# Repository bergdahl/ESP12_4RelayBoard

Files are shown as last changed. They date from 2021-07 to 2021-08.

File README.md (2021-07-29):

# ESP12_4RelayBoard

This is a simple ESP-12 based 4 relay board I designed to be used in Home Assistant. It is powered by 5V over a micro USB connector,
and switches loads at up to the rated voltage of the relay - 28V/10A, although I recommend limiting the power to max 6 Amps per channel.
Also, the screw connectors used are rated at maximum 15A, so you need to keep the _total combined_ power usage under that limit.

> NOTE: This PCB is _NOT_ designed to be used for mains voltage!

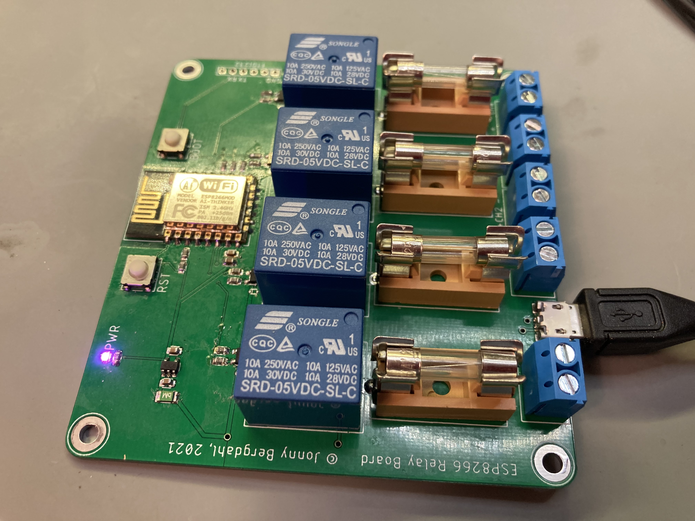
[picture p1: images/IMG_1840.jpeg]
Board


## PCB files

I have added the Gerber files in the `PCB/Gerber` folder, just zip and upload to your favorite PCB manufacturer.

I have also included the EAGLE design files if you need to modify the design for yoyr needs.

## Firmware

I use ESPHome to set it up, which is the easiest way for it to show up in Home Assistant. 

Change the `esphome` section to this:

```
esphome:
  name: relay1
  platform: ESP8266
  board: esp12e
```
Add the following section to add the relays as switches in Home Assistant.

```
switch:
  - platform: gpio
    name: "Relay1"
    pin: GPIO4
  - platform: gpio
    name: "Relay2"
    pin: GPIO5
  - platform: gpio
    name: "Relay3"
    pin: GPIO12
  - platform: gpio
    name: "Relay4"
    pin: GPIO13
```

### Flashing the board

You will need a USB-Serial adapter for initial upload of the firmware, and use the [ESPHome-Flasher](https://github.com/esphome/esphome-flasher) flashing utility.

 - Compile and download the firmware to your local machine.
 - Connect the serial adapter to the board, the board is designed for the pinout of standard FT232RL adapters.
 - Hold down the BOOT button, tap the RST button and then let go of RST. This puts the ESP-12 module in bootloader mode ready for firmware upload.
 - Start ESPHome-Flasher, select the firmware file and the proper COM port and click _Flash ESP_.

## Enclosure

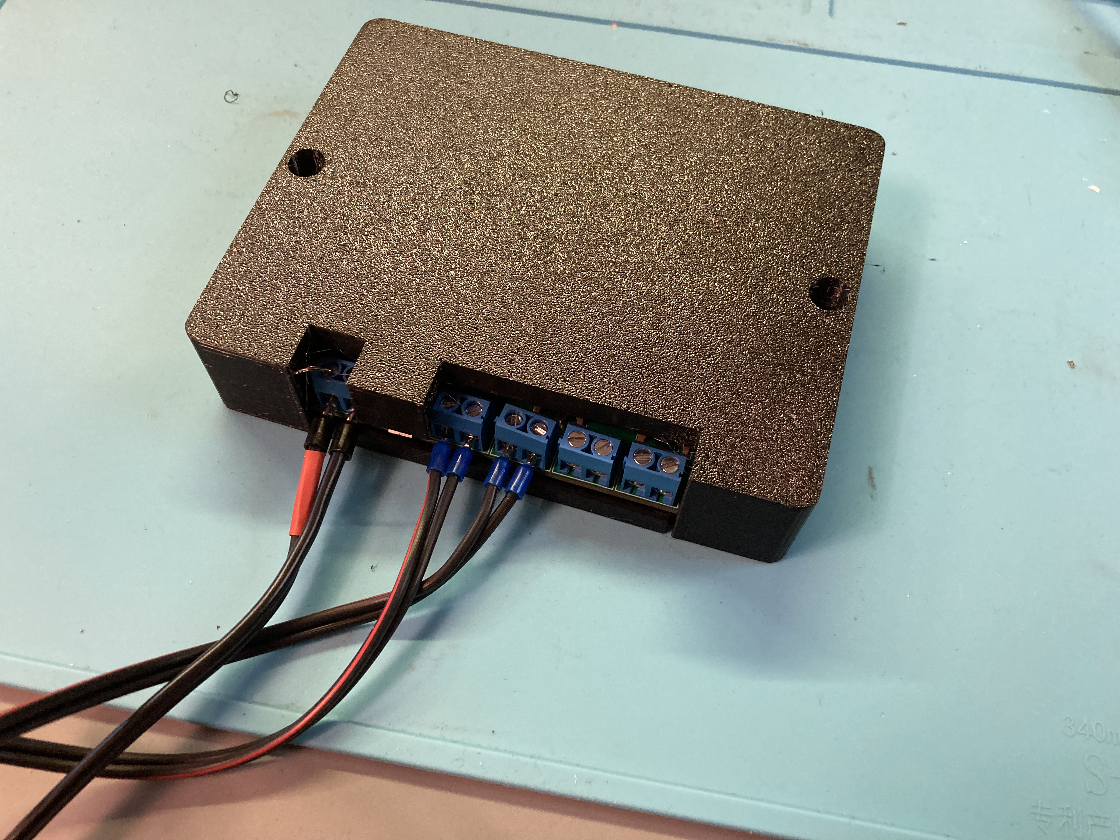
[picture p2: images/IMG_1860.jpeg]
Enclosure


I designed a simple enclosure for 3D printing, available as STL files in the `Enclosure` folder. 

I also included the Fusion360 design file if you need to modify the design for your usage.

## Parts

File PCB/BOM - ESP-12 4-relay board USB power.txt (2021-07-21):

Qty Value            Device                        Package              Parts                                 Description                                                                                   
4   100R             RESISTOR0603                  R0603                R5, R7, R9, R11                                                                                                                     
1   100nF            CAPC0603                      C0603                C4                                                                                                                                  
1   100uF            CAPC0603                      C0603                C1                                                                                                                                  
9   10K              RESISTOR0603                  R0603                R1, R2, R3, R4, R6, R8, R10, R12, R15                                                                                               
1   1K               RESISTOR0603                  R0603                R13                                                                                                                                 
4   1N4148WX-TP      DIODE1N4148WX-TP              SOD-323              D1, D2, D3, D4                                                                                                                      
2   1uF              CAPC0603                      C0603                C2, C3                                                                                                                              
4   2N7702P          MOSFET-NCHSOT23-3             SOT23-3              Q1, Q2, Q3, Q4                                                                                                                      
1   500mA            PTC0ZCJ                       PTC-0ZCJ-1206        F5                                                                                                                                  
1   AP2112K-3.3TRG1  REGULATOR-AP2112KK-SOT23-5    SOT23-5              U2                                                                                                                                  
1   BOOT             TACT-SWITCHEVQ                TACT-SWITCH-EVQ      X1                                                                                                                                  
1   ESP-12           ESP-12E                       ESP-12E              U1                                                                                                                                  
4   FUSE             FUSETEAL                      FUSE-TEAL            F1, F2, F3, F4                        https://www.aliexpress.com/item/1005001704678944.html                                                                                              
1   HEADER-FTDI232   HEADER-FTDI232                FTDI232-1X06         X4                                                                                                                                  
1   IN               TERMINAL-1X02-5.08OSTTC022162 ONSHORE-OSTTC022162  J3                                    https://www.digikey.se/product-detail/sv/on-shore-technology-inc/OSTTC022162/ED2609-ND/614558 
4   MOUNTHOLE-PAD3.2 MOUNTHOLE-PAD3.2              3.2-PAD              H1, H2, H3, H4                                                                                                                      
1   OUT1             TERMINAL-1X02-5.08OSTTC022162 ONSHORE-OSTTC022162  J1                                    https://www.digikey.se/product-detail/sv/on-shore-technology-inc/OSTTC022162/ED2609-ND/614558 
1   OUT2             TERMINAL-1X02-5.08OSTTC022162 ONSHORE-OSTTC022162  J2                                    https://www.digikey.se/product-detail/sv/on-shore-technology-inc/OSTTC022162/ED2609-ND/614558 
1   OUT3             TERMINAL-1X02-5.08OSTTC022162 ONSHORE-OSTTC022162  J4                                    https://www.digikey.se/product-detail/sv/on-shore-technology-inc/OSTTC022162/ED2609-ND/614558 
1   OUT4             TERMINAL-1X02-5.08OSTTC022162 ONSHORE-OSTTC022162  J5                                    https://www.digikey.se/product-detail/sv/on-shore-technology-inc/OSTTC022162/ED2609-ND/614558 
1   PINK             LED0603                       LED0603              D5                                    LED (Generic)                                                                                 
1   RST              TACT-SWITCHEVQ                TACT-SWITCH-EVQ      X2                                    https://www.digikey.se/product-detail/sv/panasonic-electronic-components/EVQ-Q2Y03W/P12961SCT-ND/762951
4   SRD-05VDC-SL-C   RELAYSRD-05VDC-SL-C           RELAY-SRD-05VDC-SL-C K1, K2, K3, K4                        https://www.aliexpress.com/wholesale?SearchText=SRD-05VDC-SL-C
1   USB-MICRO-B-FCI  USB-MICRO-B-FCI               USB-MICRO-B-FCI      X3                                    https://www.digikey.se/product-detail/sv/amphenol-icc-fci/10118192-0001LF/609-4613-1-ND/2785378

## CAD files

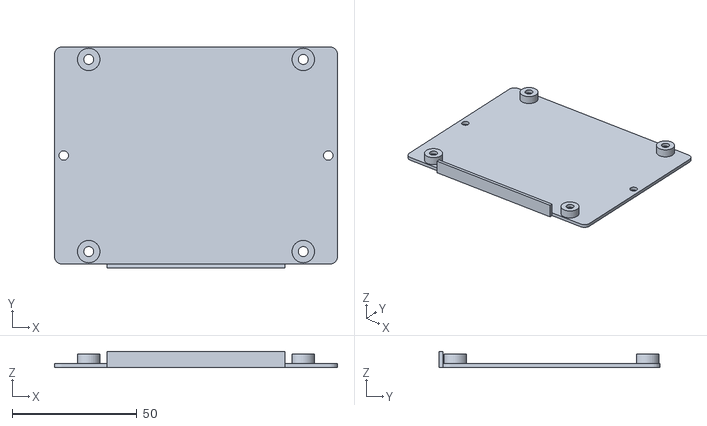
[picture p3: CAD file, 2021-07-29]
Enclosure/ESP-12 4-Relay Board 5V Enclosure - Bottom.stl
113.4 x 88.6 x 6.60

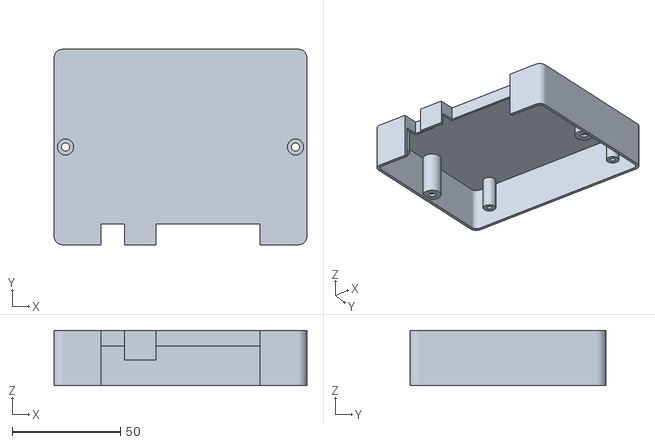
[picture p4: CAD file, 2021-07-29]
Enclosure/ESP-12 4-Relay Board 5V Enclosure - Top.stl
116.6 x 90.2 x 25.4

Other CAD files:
Enclosure/ESP-12 4-Relay Board 5V Enclosure.f3d

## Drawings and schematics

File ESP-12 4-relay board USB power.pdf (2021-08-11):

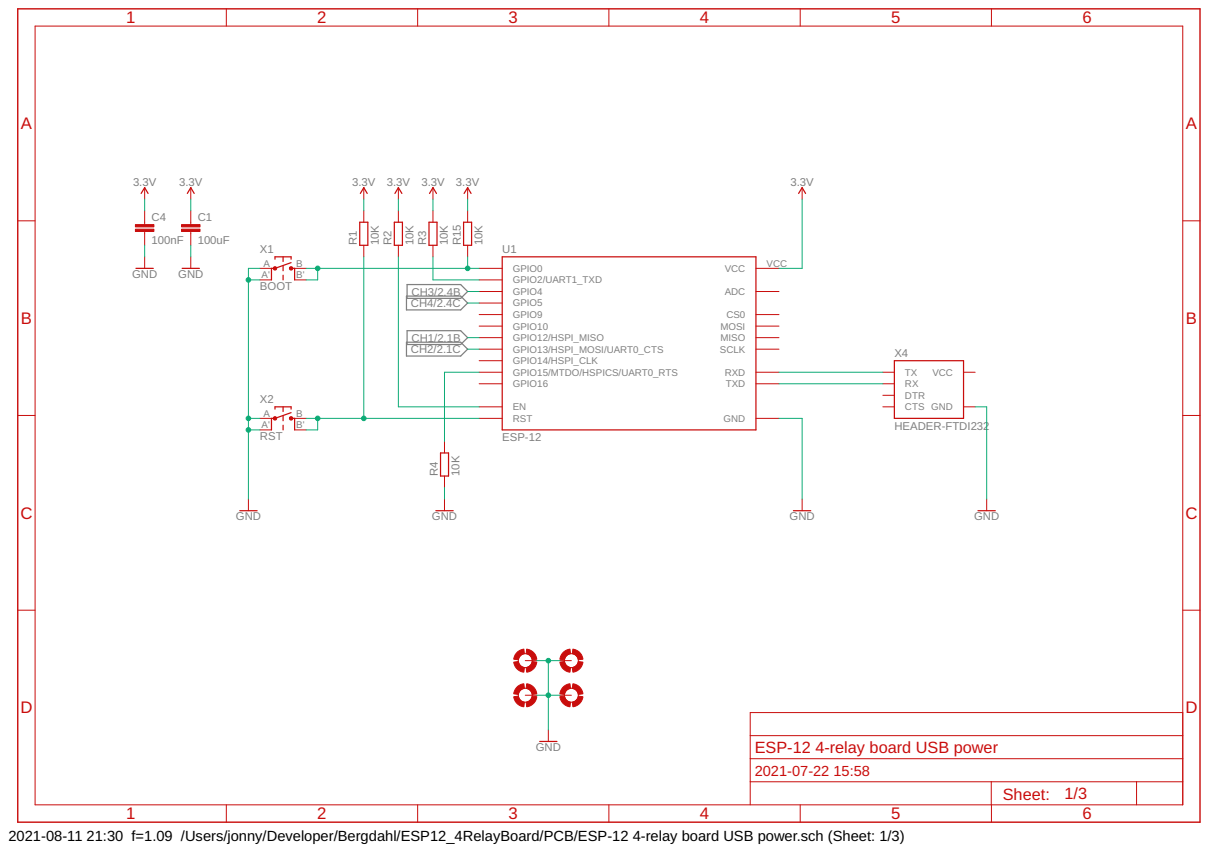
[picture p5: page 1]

ESP-12 4-relay board USB power

2021-08-11 21:30 f=1.09 /Users/jonny/Developer/Bergdahl/ESP12_4RelayBoard/PCB/ESP-12 4-relay board USB power.sch (Sheet: 1/3)

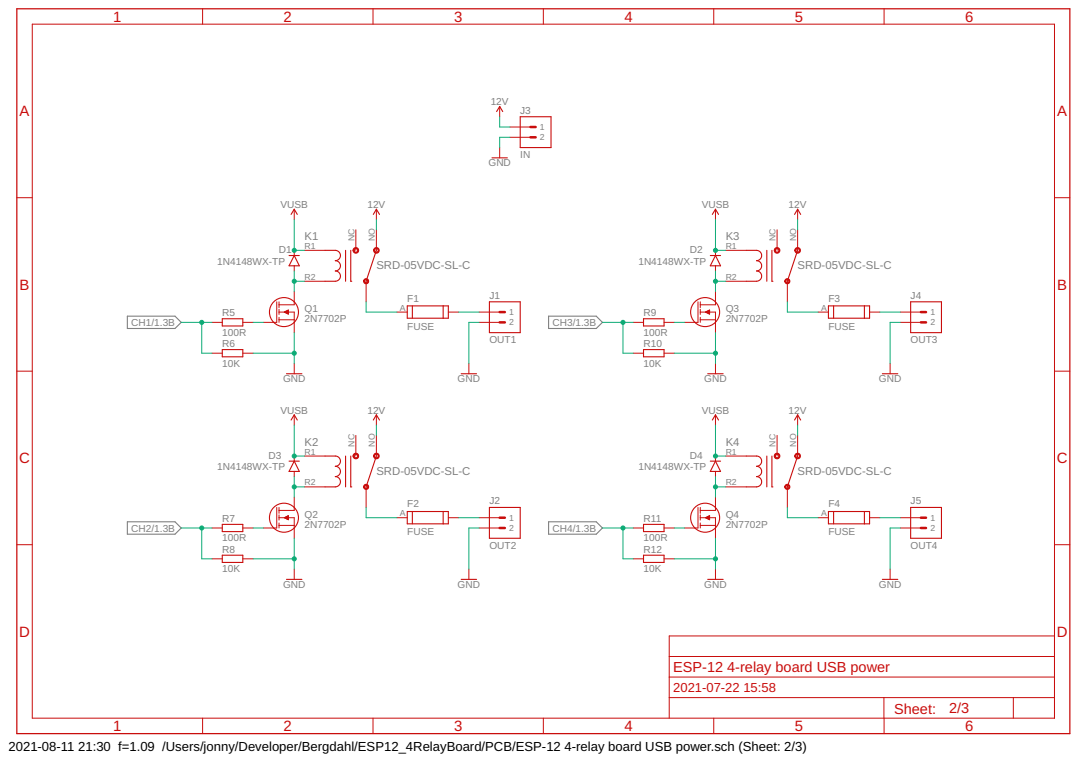
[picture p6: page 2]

ESP-12 4-relay board USB power

2021-08-11 21:30 f=1.09 /Users/jonny/Developer/Bergdahl/ESP12_4RelayBoard/PCB/ESP-12 4-relay board USB power.sch (Sheet: 2/3)

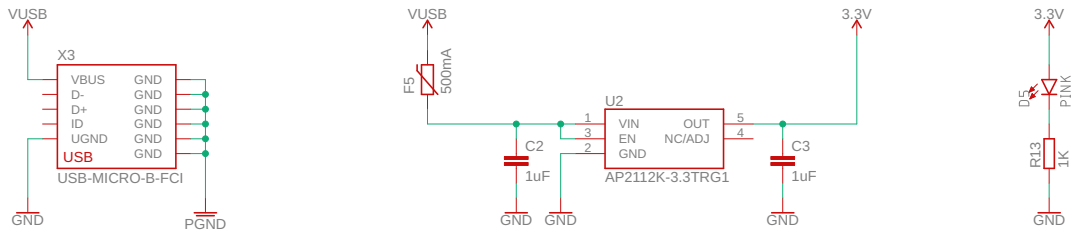
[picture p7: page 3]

ESP-12 4-relay board USB power

2021-08-11 21:30 f=1.09 /Users/jonny/Developer/Bergdahl/ESP12_4RelayBoard/PCB/ESP-12 4-relay board USB power.sch (Sheet: 3/3)

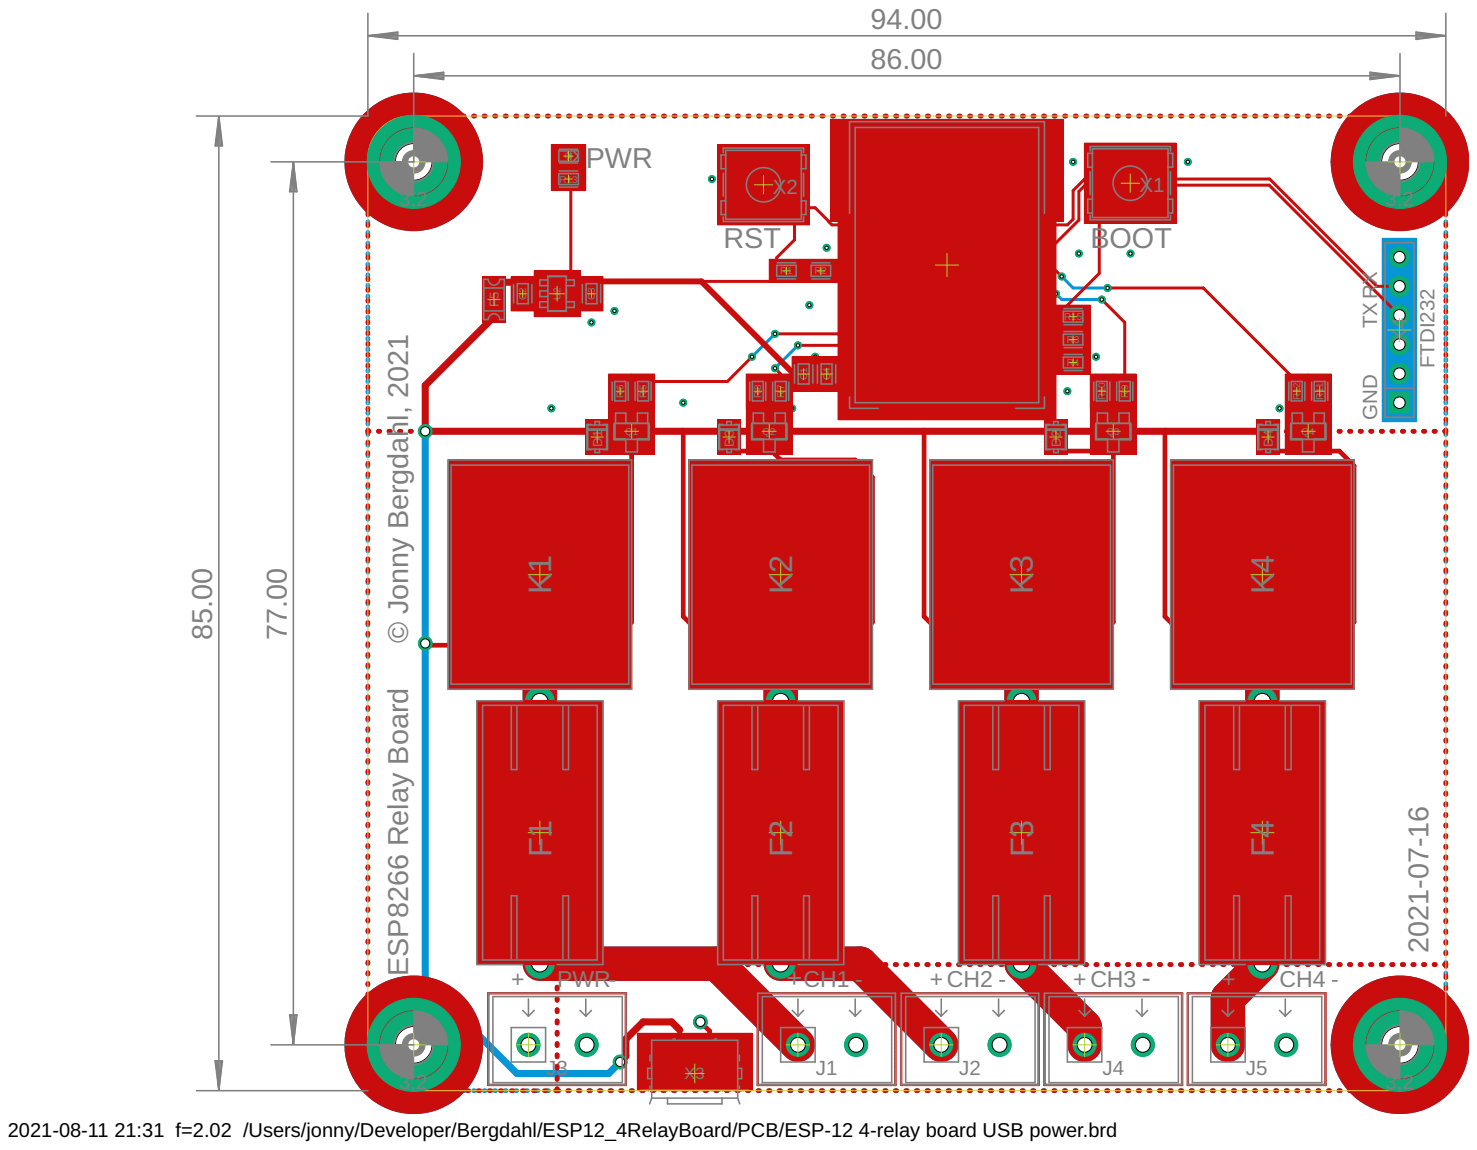
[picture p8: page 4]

2021-08-11 21:31 f=2.02 /Users/jonny/Developer/Bergdahl/ESP12_4RelayBoard/PCB/ESP-12 4-relay board USB power.brd

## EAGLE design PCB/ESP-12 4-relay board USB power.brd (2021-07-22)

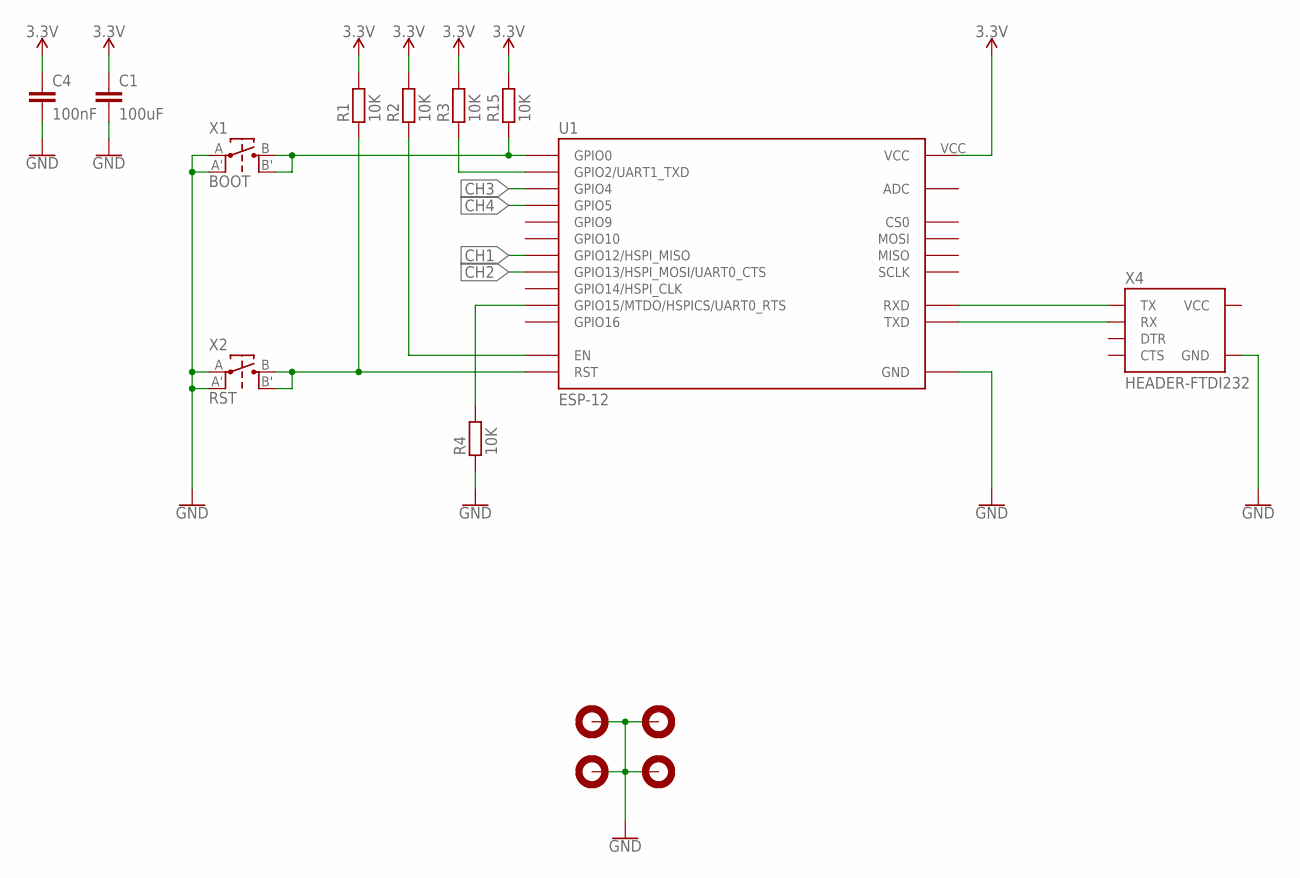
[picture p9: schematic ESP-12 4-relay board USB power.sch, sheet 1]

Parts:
C1: 100uF; C0603
C4: 100nF; C0603
H1, H2, H3, H4: MOUNTHOLE-PAD3.2; 3.2-PAD
R1, R2, R3, R4, R15: 10K; R0603
U1: ESP-12; ESP-12E
X1: BOOT; TACT-SWITCH-EVQ
X2: RST; TACT-SWITCH-EVQ
X4: HEADER-FTDI232; FTDI232-1X06

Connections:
3.3V: C1.1, C4.1, R1.2, R2.2, R3.2, R15.2, U1.VCC; also elsewhere on the board
CH1: U1.GPIO12 (GPIO12/HSPI_MISO); also elsewhere on the board
CH2: U1.GPIO13 (GPIO13/HSPI_MOSI/UART0_CTS); also elsewhere on the board
CH3: U1.GPIO4; also elsewhere on the board
CH4: U1.GPIO5; also elsewhere on the board
GND: C1.2, C4.2, H1.B3,2, H2.B3,2, H3.B3,2, H4.B3,2, R4.1, U1.GND, X1.A, X1.A', X2.A, X2.A', X4.GND; also elsewhere on the board
unnamed: R4.2, U1.GPIO15 (GPIO15/MTDO/HSPICS/UART0_RTS)
unnamed: R2.1, U1.EN
unnamed: R1.1, U1.RST, X2.B, X2.B'
unnamed: R15.1, U1.GPIO0, X1.B, X1.B'
unnamed: R3.1, U1.GPIO2 (GPIO2/UART1_TXD)
RXD: U1.RXD, X4.TX
TXD: U1.TXD, X4.RX
VCC: X4.VCC

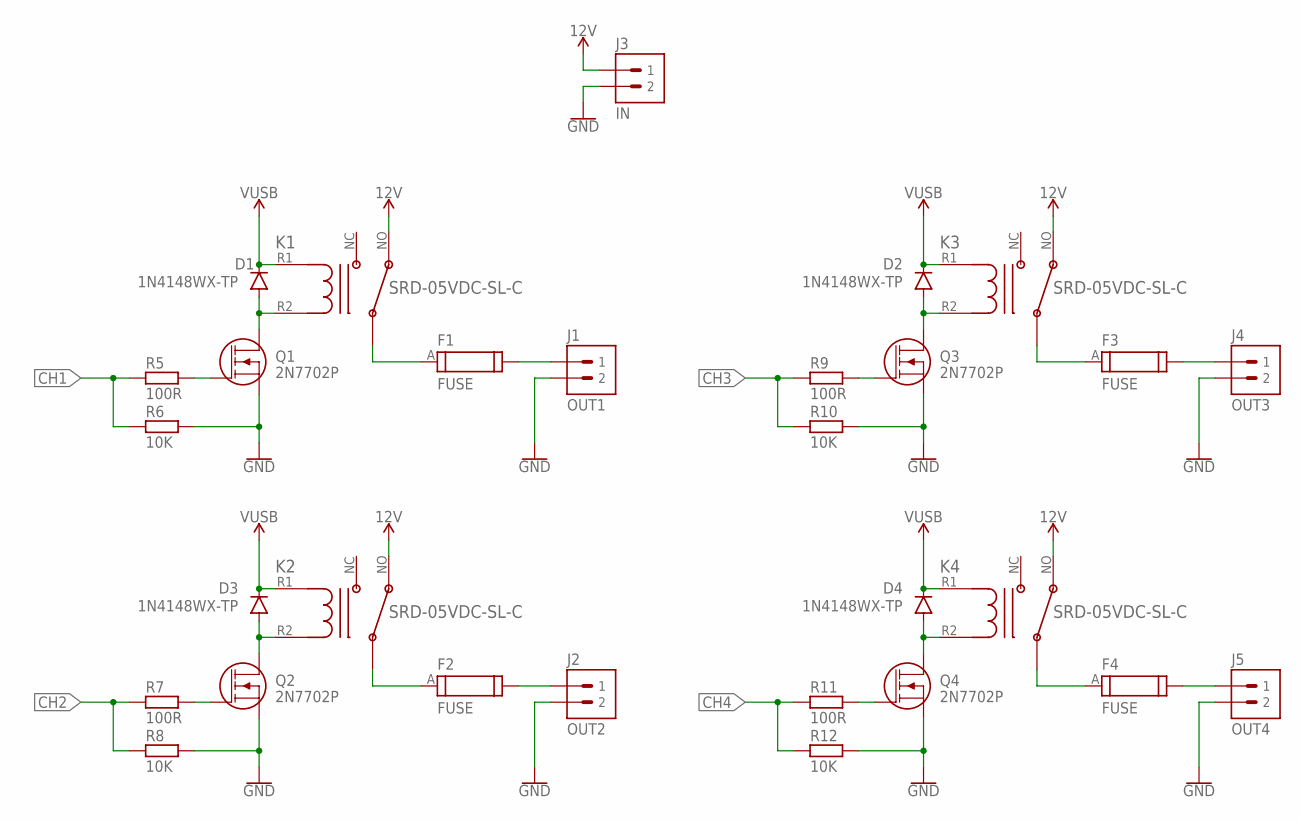
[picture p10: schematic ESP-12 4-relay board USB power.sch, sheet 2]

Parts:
D1, D2, D3, D4: 1N4148WX-TP; SOD-323
F1, F2, F3, F4: FUSE; FUSE-TEAL
J1: OUT1; ONSHORE-OSTTC022162
J2: OUT2; ONSHORE-OSTTC022162
J3: IN; ONSHORE-OSTTC022162
J4: OUT3; ONSHORE-OSTTC022162
J5: OUT4; ONSHORE-OSTTC022162
K1, K2, K3, K4: SRD-05VDC-SL-C; RELAY-SRD-05VDC-SL-C
Q1, Q2, Q3, Q4: 2N7702P; SOT23-3
R5, R7, R9, R11: 100R; R0603
R6, R8, R10, R12: 10K; R0603

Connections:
12V: J3.1, K1.NO (NC), K2.NO (NC), K3.NO (NC), K4.NO (NC)
CH1: R5.1, R6.1; also elsewhere on the board
CH2: R7.1, R8.1; also elsewhere on the board
CH3: R9.1, R10.1; also elsewhere on the board
CH4: R11.1, R12.1; also elsewhere on the board
GND: J1.2, J2.2, J3.2, J4.2, J5.2, Q1.2 (S), Q2.2 (S), Q3.2 (S), Q4.2 (S), R6.2, R8.2, R10.2, R12.2; also elsewhere on the board
unnamed: D1.2 (A), K1.R2, Q1.3 (D)
unnamed: F1.A, K1.C
unnamed: F1.B, J1.1
unnamed: Q1.1 (G), R5.2
unnamed: D3.2 (A), K2.R2, Q2.3 (D)
unnamed: Q2.1 (G), R7.2
unnamed: F2.A, K2.C
unnamed: F2.B, J2.1
unnamed: D2.2 (A), K3.R2, Q3.3 (D)
unnamed: F3.A, K3.C
unnamed: F3.B, J4.1
unnamed: Q3.1 (G), R9.2
unnamed: D4.2 (A), K4.R2, Q4.3 (D)
unnamed: Q4.1 (G), R11.2
unnamed: F4.A, K4.C
unnamed: F4.B, J5.1
VUSB: D1.1 (C), D2.1 (C), D3.1 (C), D4.1 (C), K1.R1, K2.R1, K3.R1, K4.R1; also elsewhere on the board

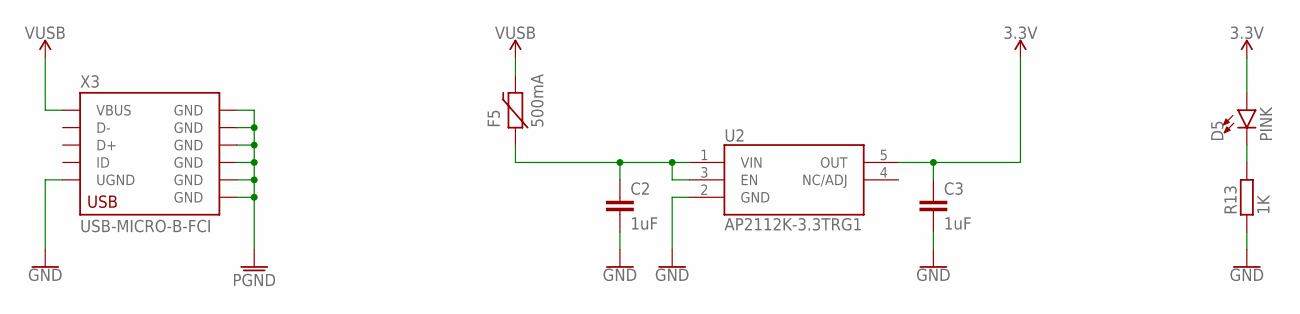
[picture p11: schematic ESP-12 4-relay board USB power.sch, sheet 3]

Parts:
C2, C3: 1uF; C0603
D5: PINK; LED0603
F5: 500mA; PTC-0ZCJ-1206
R13: 1K; R0603
U2: AP2112K-3.3TRG1; SOT23-5
X3: USB-MICRO-B-FCI

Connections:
3.3V: C3.1, D5.A, U2.5 (OUT); also elsewhere on the board
GND: C2.2, C3.2, R13.1, U2.2 (GND), X3.5 (UGND); also elsewhere on the board
unnamed: D5.C, R13.2
unnamed: C2.1, F5.1, U2.1 (VIN), U2.3 (EN)
PGND: X3.GND@1 (GND), X3.GND@2 (GND), X3.GND@3 (GND), X3.GND@4 (GND), X3.GND@5 (GND), X3.GND@6 (GND)
VUSB: F5.2, X3.1 (VBUS); also elsewhere on the board

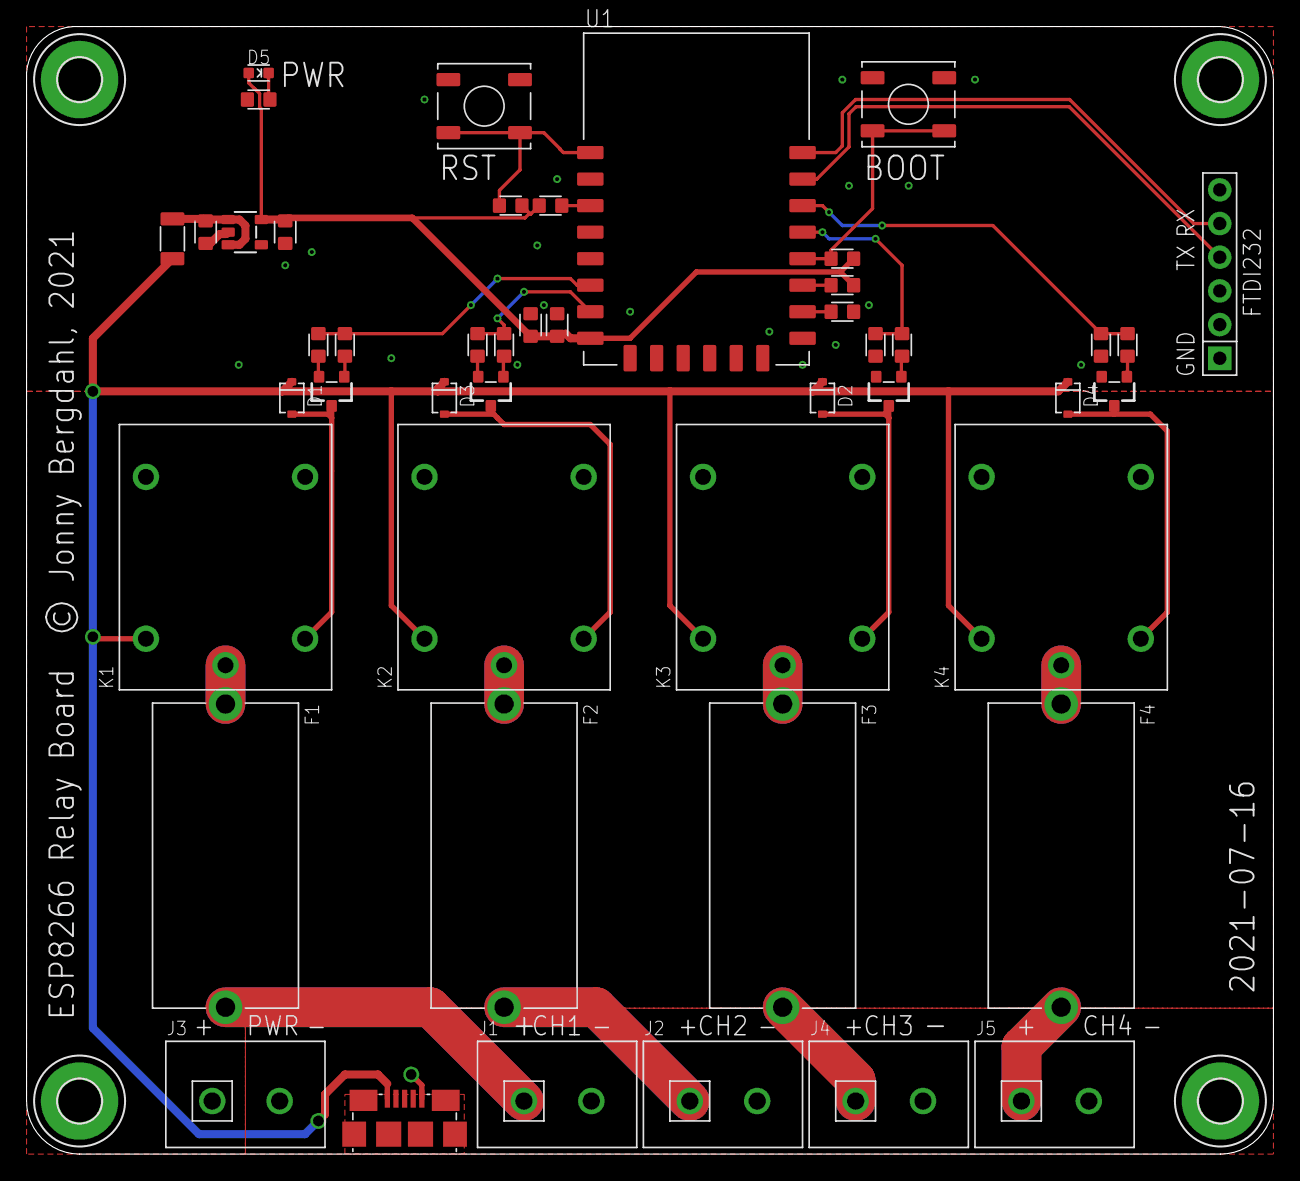
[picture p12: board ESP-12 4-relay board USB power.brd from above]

Board: 2 copper layers, 94.0 x 85.0 mm, 51 parts (0 on the bottom side), 34 nets.

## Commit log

2021-07-22 Switch NC and NO on relays
    [ESP-12 4-relay board USB power.brd, ESP-12 4-relay board USB power.sch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]
2021-07-29 New enclosure
    [ESP-12 4-Relay Board 5V Enclosure - Bottom.stl, ESP-12 4-Relay Board 5V Enclosure - Top.stl, ESP-12 4-Relay Board 5V Enclosure.f3d]

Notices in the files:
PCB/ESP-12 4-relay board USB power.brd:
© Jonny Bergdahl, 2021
